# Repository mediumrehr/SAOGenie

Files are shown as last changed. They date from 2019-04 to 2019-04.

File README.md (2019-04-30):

# SAOGenie

The SAO Genie was inspired by the [TPM Genie](https://github.com/nccgroup/TPMGenie), specially crafted for attacking [Shitty Add-ons](https://hackaday.com/2018/06/21/this-is-the-year-conference-badges-get-their-own-badges/) at DEF CON 26. The SAO Genie was designed as a tool for electronic badge and add-on hacking, since it provides an easier interface for sniffing and manipulating data on the serial bus between a badge and targeted add-on. As electronic badges are being used more frequently in conference hacking challenges, the SAO Genie is geared to make it easier to dig into inter-badge/add-on communications.

The SAO Genie works by sitting between an electronic badge and a targeted add-on as a man-in-the-middle kind of way. The SAO Genie is able to do this by acting as a slave to the conference badge, pretending to be the targeted add-on (using the same i2c address), while also playing the role of master to the targeted add-on (forwarding and possibly manipulating) serial data packets between the badge and target add-on. The SAO Genie has both a 2x2 male header for plugging into a conference badge, and a 2x2 female header for providing a connector for the targeted add-on to connect to.

## Functionality

Currently, only monitor/passthrough mode is supported.

#### Monitor/Passthrough Mode

When placed between an electronic badge and targeted add-on, the SAO Genie will forward all communications between the type pieces of hardware, while also repeating any data out through the UART serial port.

Connect the SAO Genie as shown below:

To connect to the UART serial port, attach your serial reader to the RX, TX, and GND pins on the 'handle'.

Serial settings:

```
Baudrate: 9600
Data bits: 8
Parity: None
Stop bits: 1
```

## Installing/Updating Firmware

### Setup

Firmware can be loaded with [Atmel Studio 7.0](https://www.microchip.com/mplab/avr-support/atmel-studio-7), or install the packages below to use with your preferred text editor and compile with arm gcc.

#### arm gcc and gdb

MacOS

```
brew install armmbed/formulae/arm-none-eabi-gcc
```

#### jlink gdb server

Download install file from [segger.com](https://www.segger.com/products/debug-probes/j-link/tools/j-link-gdb-server/about-j-link-gdb-server/)

#### SWD connection

Software debug (SWD) pins are labelled on the back of the board. Connect SWDIO, SWCLK, 3V3, RESET, and GND as labelled. SWD requires the board to be powered external from the SWD port, so it's easiest to power the board from the 3V3 and GND pins on one of the SAO headers.

### Build

```
cd firmware/SAOGenie/
make -C Build/
```

### Load

#### jlink

Start jlink gdb server in one tab

```
JLinkGDBServer -if SWD -device ATSAMD21G18
```

Start gdb in another tba

```
arm-none-eabi-gdb Build/SAOGenie.elf
(gdb) target extended-remote :2331
```

Load new firmware, reset microcontroller, and run new code

```
(gdb) load
(gdb) monitor reset
(gdb) c
```

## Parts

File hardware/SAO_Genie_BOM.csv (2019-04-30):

DEF CON 26 SAO Genie Add-on Bill of Materials
April 2019
@mediumrehr
Part | Value | Package | Part Number | Description | Digikey link | notes
C6, 8, 10-12 | 0.1uF | 603 |  | Capacitor
C7, 9 | 22pF | 603 |  | Capacitor
D1 | amber | 1206 |  | LED
J1 | 2x2 | 0.1" pitch |  | SAO Male header Connector
J2 | 2x2 | 0.1" pitch |  | SAO Female header Connector
L1 | FB - 30Ohm | 603 |  | Inductor
R3, 4, 11 | 10K | 805 |  | Resistor
R5 | 68 | 603 |  | Resistor
U4 |  | 48-TQFP | ATSAMD21G18A | IC MCU 32BIT 256KB FLASH | https://www.digikey.com/product-detail/en/microchip-technology/ATSAMD21G18A-AUT/ATSAMD21G18A-AUTCT-ND/4878879
Y1 | 32.768KHz | 2-SMD | ABS06-127-32.768KHZ-T | Crystal | https://www.digikey.com/product-detail/en/abracon-llc/ABS06-127-32.768KHZ-T/535-14513-1-ND/8827204

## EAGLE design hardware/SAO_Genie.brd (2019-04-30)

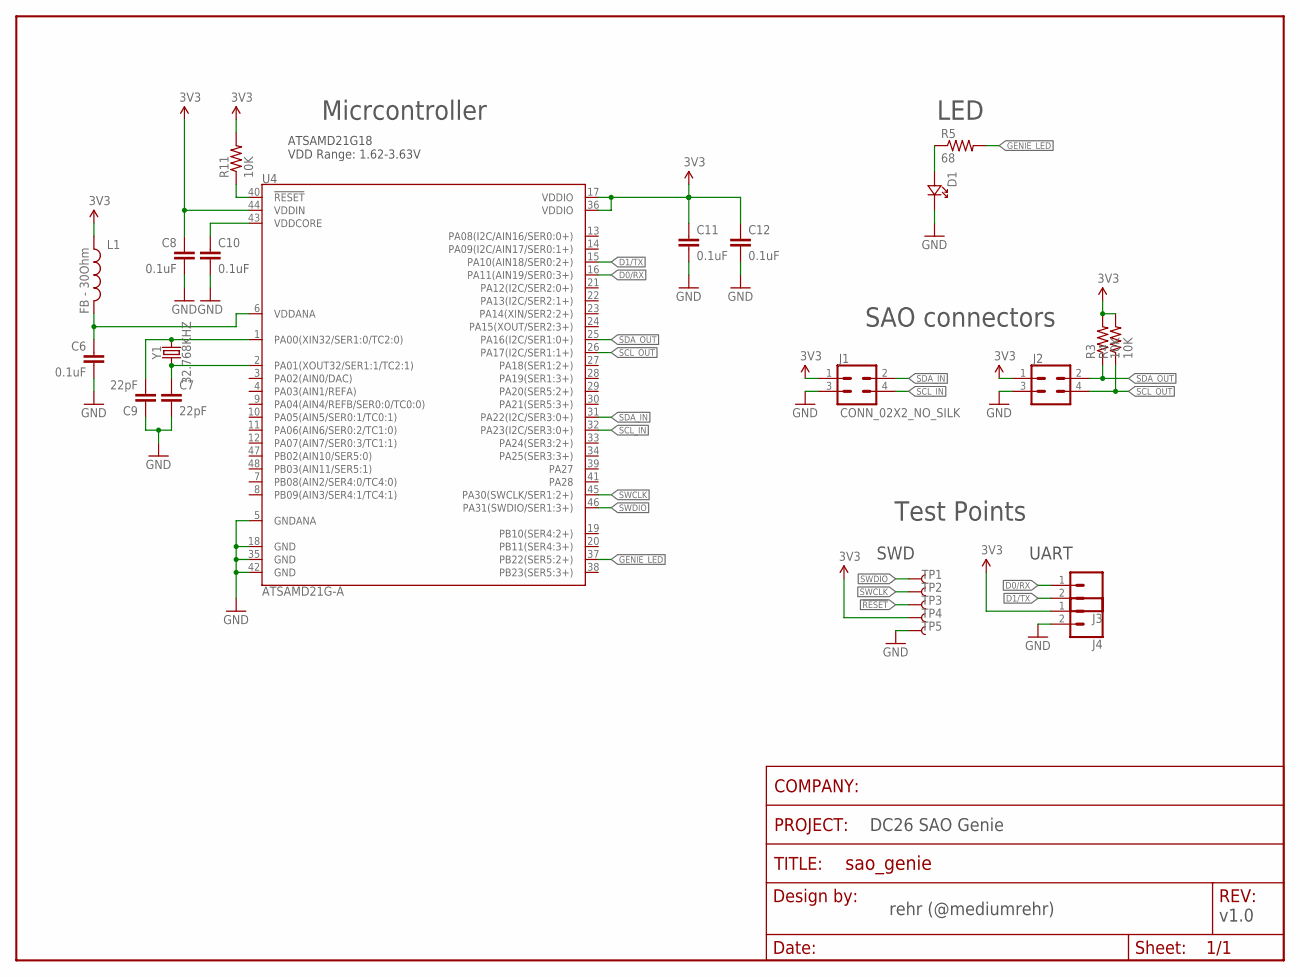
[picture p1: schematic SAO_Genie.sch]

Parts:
C6, C8, C10, C11, C12: 0.1uF; 0603-CAP
C7, C9: 22pF; 0603-CAP
D1: LED1206REVERSE_NO_SILK; 1206_NO_SILK
FRAME1: FRAME-LETTER-BLANKNO_PACKAGE; DUMMY
J1: CONN_02X2_NO_SILK; 2X2_NO_SILK
J2: SAO OUT; 2X2_NO_SILK
J3, J4: CONN_021X02_NO_SILK; 1X02_NO_SILK
L1: FB - 30Ohm; 0603
R3, R4, R11: 10K; 0603-RES
R5: 68; 0603-RES
TP1, TP2, TP3, TP4, TP5: TEST-POINT3X5; PAD.03X.05
U4: ATSAMD21G-A; TQFP-48
Y1: 32.768KHZ; ABS06

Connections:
3.3V: C8.1, C11.1, C12.1, J1.1, J2.1, J4.1, L1.1, R3.2, R4.2, R11.2, TP4.P$1, U4.17 (VDDIO), U4.36 (VDDIO), U4.44 (VDDIN)
!RESET: R11.1, TP3.P$1, U4.40 (!RESET!)
D0/RX: J3.1, U4.16 (PA11(AIN19/SER0:3+))
D1/TX: J3.2, U4.15 (PA10(AIN18/SER0:2+))
GENIE_LED: R5.2, U4.37 (PB22(SER5:2+))
GND: C6.2, C7.2, C8.2, C9.1, C10.2, C11.2, C12.2, D1.P$1, J1.3, J2.3, J4.2, TP5.P$1, U4.5 (GNDANA), U4.18 (GND), U4.35 (GND), U4.42 (GND)
unnamed: C7.1, U4.2 (PA01(XOUT32/SER1:1/TC2:1)), Y1.P$1 (1)
unnamed: D1.P$2, R5.1
unnamed: C9.2, U4.1 (PA00(XIN32/SER1:0/TC2:0)), Y1.P$2 (2)
SCL_IN: J1.4, U4.32 (PA23(I2C/SER3:0+))
SCL_OUT: J2.4, R4.1, U4.26 (PA17(I2C/SER1:1+))
SDA_IN: J1.2, U4.31 (PA22(I2C/SER3:0+))
SDA_OUT: J2.2, R3.1, U4.25 (PA16(I2C/SER1:0+))
SWCLK: TP2.P$1, U4.45 (PA30(SWCLK/SER1:2+))
SWDIO: TP1.P$1, U4.46 (PA31(SWDIO/SER1:3+))
VDDANA: C6.1, L1.2, U4.6 (VDDANA)
VDDCORE: C10.1, U4.43 (VDDCORE)

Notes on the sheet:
ATSAMD21G18 VDD Range: 1.62-3.63V
DC26 SAO Genie
rehr (@mediumrehr)
v1.0
Micrcontroller
LED
SAO connectors
Test Points
SWD
UART

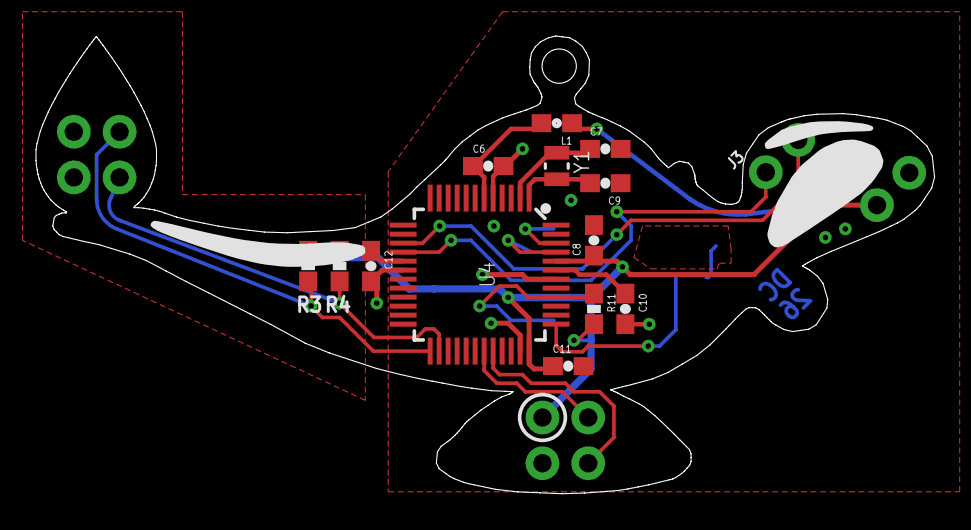
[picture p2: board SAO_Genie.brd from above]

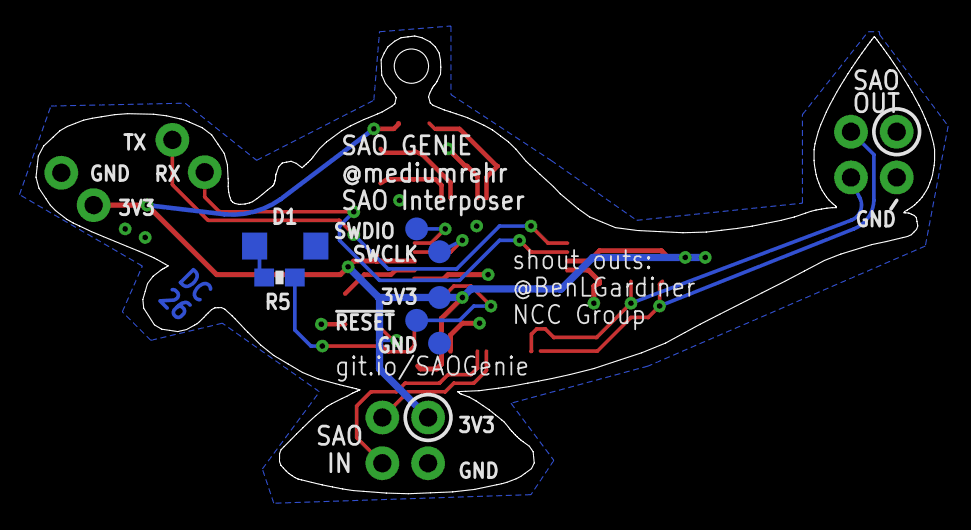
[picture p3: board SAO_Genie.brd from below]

Board: 2 copper layers, 49.9 x 25.4 mm, 25 parts (7 on the bottom side), 17 nets.

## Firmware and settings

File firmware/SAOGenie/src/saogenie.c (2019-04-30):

/**
 * 
 * SAOGenie
 * Shitty add-on hacking tool
 * Rob Rehr
 * @mediumrehr
 *
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
 * 3. The name of Atmel may not be used to endorse or promote products derived
 *    from this software without specific prior written permission.
 *
 * 4. This software may only be redistributed and used in connection with an
 *    Atmel microcontroller product.
 *
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
 */

#include <asf.h>
#include <stdio.h>
#include <string.h>

void i2c_read_request_callback(struct i2c_slave_module *const module);
void i2c_slave_read_complete_callback(struct i2c_slave_module *const module);
void i2c_write_request_callback(struct i2c_slave_module *const module);
void i2c_slave_write_complete_callback(struct i2c_slave_module *const module);
void usart_read_callback(struct usart_module *const usart_module);
void usart_write_callback(struct usart_module *const usart_module);
void i2c_write_complete_callback(struct i2c_master_module *const module);

void configure_i2c_slave(void);
void configure_i2c_slave_callbacks(void);
void configure_i2c_master(void);
void configure_i2c_master_callbacks(void);
void configure_usart(void);
void configure_usart_callbacks(void);

void set_genie_mode(uint8_t new_mode);

// i2c packets
#define PACKET_BUFFER_SIZE 50
static uint8_t dest_addr = 0;
static struct i2c_slave_packet packet_in;
struct i2c_master_packet wr_packet_out;
struct i2c_master_packet rd_packet_out;

#define DATA_LENGTH 50
static uint8_t write_buffer_in[DATA_LENGTH];
static uint8_t read_buffer_in [DATA_LENGTH];

static uint8_t write_buffer_out[DATA_LENGTH];
static uint8_t read_buffer_out[DATA_LENGTH];

// SAO Genie mode definitions
#define GENIE_MODE_OFF 			0
#define GENIE_MODE_PASSTHROUGH 	1
#define GENIE_MODE_REDIRECT		2 // not implememnted
#define GENIE_MODE_INJECT		3 // not implemented

uint8_t genie_mode = GENIE_MODE_OFF;

// Init device instance
struct i2c_slave_module i2c_slave_instance;
struct i2c_master_module i2c_master_instance;
struct usart_module usart_instance;

#define MAX_RX_BUFFER_LENGTH   1
volatile uint8_t rx_buffer[MAX_RX_BUFFER_LENGTH];

void i2c_read_request_callback(struct i2c_slave_module *const module) {
	// Init i2c packet
	packet_in.data_length = DATA_LENGTH;
	packet_in.data        = write_buffer_in;

	// Write buffer to master
	i2c_slave_write_packet_job(module, &packet_in);
}

void i2c_write_request_callback(struct i2c_slave_module *const module) {	
	// init i2c packet
	packet_in.data_length = DATA_LENGTH;
	packet_in.data        = read_buffer_in;
	
	// store intended destination for packet
	dest_addr = module->hw->I2CS.DATA.reg >> 1;

	// read buffer from master
	i2c_slave_read_packet_job(module, &packet_in);
}

void i2c_slave_write_complete_callback(struct i2c_slave_module *const module) {
	uint8_t temp[] = "test";
	usart_write_buffer_wait(&usart_instance, temp, sizeof(temp));
}

void i2c_slave_read_complete_callback(struct i2c_slave_module *const module) {
	// make sure SAO Genie mode is not set to off
	if (genie_mode == GENIE_MODE_PASSTHROUGH) {
		// turn i2c LED on to show activity
		port_pin_set_output_level(LEDI2C_PIN, true);
		
		// copy serial data locally to pass along
		uint8_t genie_dest_addr = dest_addr;
		uint8_t bytes_received = module->buffer_received;
		
		// copy destination and data to output packet for master to send
		wr_packet_out.address	  = genie_dest_addr;
		wr_packet_out.data_length = bytes_received;
		wr_packet_out.data        = &read_buffer_in[0];

		// send output packet out master
		i2c_master_write_packet_wait(&i2c_master_instance, &wr_packet_out);

		// print i2c direction and addresses
		char dirStr[29] = {0};
		snprintf(dirStr, sizeof(dirStr), "| Host > Genie > 0x%02X       ", genie_dest_addr);
		usart_write_buffer_wait(&usart_instance, dirStr, sizeof(dirStr));

		// print i2c data captured to uart
		usart_write_buffer_wait(&usart_instance, "| ", sizeof("| "));
		uint8_t i = 0;
		while(read_buffer_in[i] != 0) {
			uint8_t tempStr[4] = {0};
			snprintf(tempStr, sizeof(tempStr), "%02X ", read_buffer_in[i]);
			usart_write_buffer_wait(&usart_instance, tempStr, sizeof(tempStr));
			i++;
		}
		usart_write_buffer_wait(&usart_instance, "\n", sizeof("\n"));
		
		// toggle LED to show activity
		port_pin_set_output_level(LEDI2C_PIN, false);
	}
}

void i2c_write_complete_callback(struct i2c_master_module *const module) {
	// initiate new packet read
	i2c_master_read_packet_job(&i2c_master_instance,&rd_packet_out);
}

void usart_read_callback(struct usart_module *const usart_module) {
	// no user input currently
	// major to do item
}

void usart_write_callback(struct usart_module *const usart_module) {
	
}

void configure_i2c_slave(void) {
	// initialize config for i2c slave
	struct i2c_slave_config config_i2c_slave;
	i2c_slave_get_config_defaults(&config_i2c_slave);

	// set slave to respond to any address between 0x00 and 0xFF
	config_i2c_slave.address	  = 0xFF; // upper i2c address range
	config_i2c_slave.address_mask = 0x00; // lower i2c address range
	config_i2c_slave.address_mode = I2C_SLAVE_ADDRESS_MODE_RANGE;
	config_i2c_slave.pinmux_pad0  = PINMUX_PA22C_SERCOM3_PAD0;
	config_i2c_slave.pinmux_pad1  = PINMUX_PA23C_SERCOM3_PAD1;

	// initialize and enable i2c slave with config
	while(i2c_slave_init(&i2c_slave_instance, SERCOM3, &config_i2c_slave) != STATUS_OK);
	i2c_slave_enable(&i2c_slave_instance);
}

void configure_i2c_slave_callbacks(void) {
	// Register and enable i2c slave callback functions
	i2c_slave_register_callback(&i2c_slave_instance, i2c_read_request_callback,
		I2C_SLAVE_CALLBACK_READ_REQUEST);
	i2c_slave_register_callback(&i2c_slave_instance, i2c_slave_read_complete_callback,
		I2C_SLAVE_CALLBACK_READ_COMPLETE);
	i2c_slave_register_callback(&i2c_slave_instance, i2c_write_request_callback,
		I2C_SLAVE_CALLBACK_WRITE_REQUEST);
	i2c_slave_register_callback(&i2c_slave_instance, i2c_slave_write_complete_callback,
		I2C_SLAVE_CALLBACK_WRITE_COMPLETE);

	i2c_slave_enable_callback(&i2c_slave_instance, I2C_SLAVE_CALLBACK_READ_REQUEST);
	i2c_slave_enable_callback(&i2c_slave_instance, I2C_SLAVE_CALLBACK_READ_COMPLETE);
	i2c_slave_enable_callback(&i2c_slave_instance, I2C_SLAVE_CALLBACK_WRITE_REQUEST);
	i2c_slave_enable_callback(&i2c_slave_instance, I2C_SLAVE_CALLBACK_WRITE_COMPLETE);
}

void configure_usart(void) {
	// initialize config for uart
	struct usart_config config_usart;
	usart_get_config_defaults(&config_usart);

	// set uart baudrate and uart pins
	config_usart.baudrate    = 9600;
	config_usart.mux_setting = EXT1_UART_SERCOM_MUX_SETTING;
	config_usart.pinmux_pad0 = EXT1_UART_SERCOM_PINMUX_PAD0;
	config_usart.pinmux_pad1 = EXT1_UART_SERCOM_PINMUX_PAD1;
	config_usart.pinmux_pad2 = EXT1_UART_SERCOM_PINMUX_PAD2;
	config_usart.pinmux_pad3 = EXT1_UART_SERCOM_PINMUX_PAD3;

	// initialize and enable uart with config
	while (usart_init(&usart_instance, EXT1_UART_MODULE, &config_usart) != STATUS_OK);
	usart_enable(&usart_instance);
}

void configure_usart_callbacks(void) {
	// register and enable uart callback functions
	usart_register_callback(&usart_instance,
		usart_write_callback, USART_CALLBACK_BUFFER_TRANSMITTED);
	usart_register_callback(&usart_instance,
		usart_read_callback, USART_CALLBACK_BUFFER_RECEIVED);

	usart_enable_callback(&usart_instance, USART_CALLBACK_BUFFER_TRANSMITTED);
	usart_enable_callback(&usart_instance, USART_CALLBACK_BUFFER_RECEIVED);
}

void configure_i2c_master(void) {
	// initialize config for i2c master
	struct i2c_master_config config_i2c_master;
	i2c_master_get_config_defaults(&config_i2c_master);

	// set buffer timerout and pins
	config_i2c_master.buffer_timeout = 65535;
	config_i2c_master.pinmux_pad0    = PINMUX_PA16C_SERCOM1_PAD0;
	config_i2c_master.pinmux_pad1    = PINMUX_PA17C_SERCOM1_PAD1;

	// initialize and enable i2c master with config
	while(i2c_master_init(&i2c_master_instance, SERCOM1, &config_i2c_master) != STATUS_OK);
	i2c_master_enable(&i2c_master_instance);
}

void configure_i2c_master_callbacks(void)
{
	// Register and enable i2c master callback functions
	i2c_master_register_callback(&i2c_master_instance, \
		i2c_write_complete_callback, I2C_MASTER_CALLBACK_WRITE_COMPLETE);

	i2c_master_enable_callback(&i2c_master_instance, I2C_MASTER_CALLBACK_WRITE_COMPLETE);
}

static void config_led(void) {
	// initialize config for pins
	struct port_config pin_conf;
	port_get_config_defaults(&pin_conf);

	// set direction, apply config, and set output to off
	pin_conf.direction  = PORT_PIN_DIR_OUTPUT;
	port_pin_set_config(LEDI2C_PIN, &pin_conf);
	port_pin_set_output_level(LEDI2C_PIN, false);
}

void set_genie_mode(uint8_t new_mode) {
	// switch and print new SAO Genie mode
	switch(new_mode) {
		case GENIE_MODE_PASSTHROUGH:
		; // print new mode
		uint8_t printStr1[] = "|                           | [*] mode set to: passthrough\n";
		usart_write_buffer_wait(&usart_instance, printStr1, sizeof(printStr1));
		break;

		case GENIE_MODE_REDIRECT:
		; // print new mode
		uint8_t printStr3[] = "|                           | [*] mode set to: redirect\n";
		usart_write_buffer_wait(&usart_instance, printStr3, sizeof(printStr3));
		break;

		case GENIE_MODE_INJECT:
		; // print new mode
		uint8_t printStr2[] = "|                           | [*] mode set to: inject\n";
		usart_write_buffer_wait(&usart_instance, printStr2, sizeof(printStr2));
		break;

		default:
		; // default/off
		uint8_t printStr0[] = "|                           | [*] mode set to: off\n";
		usart_write_buffer_wait(&usart_instance, printStr0, sizeof(printStr0));
		break;
	}

	genie_mode = new_mode;
}

int main(void) {

	system_init();

	configure_i2c_slave();
	configure_i2c_slave_callbacks();
	
	configure_i2c_master();
	configure_i2c_master_callbacks();
	
	configure_usart();
	configure_usart_callbacks();
	
	config_led();

	system_interrupt_enable_global();

	uint8_t aboutStr[] = "\n********************\n   SAO GENIE v0.1\n     mediumrehr\n********************\n\n";
	usart_write_buffer_wait(&usart_instance, aboutStr, sizeof(aboutStr));

	uint8_t headerStr[] = "/---------------------------|-------------------------------------------------\\\n|         Direction         |  Data                                           |\n|---------------------------|-------------------------------------------------|\n";
	usart_write_buffer_wait(&usart_instance, headerStr, sizeof(headerStr));

	set_genie_mode(GENIE_MODE_PASSTHROUGH);

	while (true) {
		// loop and wait for uart input
		usart_read_buffer_job(&usart_instance, (uint8_t *)rx_buffer, MAX_RX_BUFFER_LENGTH);
	}
}

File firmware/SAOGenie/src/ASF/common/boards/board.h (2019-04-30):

/**
 * \file
 *
 * \brief Standard board header file.
 *
 * This file includes the appropriate board header file according to the
 * defined board (parameter BOARD).
 *
 * Copyright (c) 2009-2016 Atmel Corporation. All rights reserved.
 *
 * \asf_license_start
 *
 * \page License
 *
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
 * 3. The name of Atmel may not be used to endorse or promote products derived
 *    from this software without specific prior written permission.
 *
 * 4. This software may only be redistributed and used in connection with an
 *    Atmel microcontroller product.
 *
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
 * \asf_license_stop
 *
 */
/*
 * Support and FAQ: visit <a href="http://www.atmel.com/design-support/">Atmel Support</a>
 */

#ifndef _BOARD_H_
#define _BOARD_H_

/**
 * \defgroup group_common_boards Generic board support
 *
 * The generic board support module includes board-specific definitions
 * and function prototypes, such as the board initialization function.
 *
 * \{
 */

#include "compiler.h"

#ifdef __cplusplus
extern "C" {
#endif


/*! \name Base Boards
 */
//! @{
#define EVK1100                     1  //!< AT32UC3A EVK1100 board.
#define EVK1101                     2  //!< AT32UC3B EVK1101 board.
#define UC3C_EK                     3  //!< AT32UC3C UC3C-EK board.
#define EVK1104                     4  //!< AT32UC3A3 EVK1104 board.
#define EVK1105                     5  //!< AT32UC3A EVK1105 board.
#define STK600_RCUC3L0              6  //!< STK600 RCUC3L0 board.
#define UC3L_EK                     7  //!< AT32UC3L-EK board.
#define XPLAIN                      8  //!< ATxmega128A1 Xplain board.
#define STK600_RC064X              10  //!< ATxmega256A3 STK600 board.
#define STK600_RC100X              11  //!< ATxmega128A1 STK600 board.
#define UC3_A3_XPLAINED            13  //!< ATUC3A3 UC3-A3 Xplained board.
#define UC3_L0_XPLAINED            15  //!< ATUC3L0 UC3-L0 Xplained board.
#define STK600_RCUC3D              16  //!< STK600 RCUC3D board.
#define STK600_RCUC3C0             17  //!< STK600 RCUC3C board.
#define XMEGA_B1_XPLAINED          18  //!< ATxmega128B1 Xplained board.
#define XMEGA_A1_XPLAINED          19  //!< ATxmega128A1 Xplain-A1 board.
#define XMEGA_A1U_XPLAINED_PRO     20  //!< ATxmega128A1U XMEGA-A1U Xplained Pro board.
#define STK600_RCUC3L4             21  //!< ATUCL4 STK600 board.
#define UC3_L0_XPLAINED_BC         22  //!< ATUC3L0 UC3-L0 Xplained board controller board.
#define MEGA1284P_XPLAINED_BC      23  //!< ATmega1284P-Xplained board controller board.
#define STK600_RC044X              24  //!< STK600 with RC044X routing card board.
#define STK600_RCUC3B0             25  //!< STK600 RCUC3B0 board.
#define UC3_L0_QT600               26  //!< QT600 UC3L0 MCU board.
#define XMEGA_A3BU_XPLAINED        27  //!< ATxmega256A3BU Xplained board.
#define STK600_RC064X_LCDX         28  //!< XMEGAB3 STK600 RC064X LCDX board.
#define STK600_RC100X_LCDX         29  //!< XMEGAB1 STK600 RC100X LCDX board.
#define UC3B_BOARD_CONTROLLER      30  //!< AT32UC3B1 board controller for Atmel boards.
#define RZ600                      31  //!< AT32UC3A RZ600 MCU board.
#define SAM3S_EK                   32  //!< SAM3S-EK board.
#define SAM3U_EK                   33  //!< SAM3U-EK board.
#define SAM3X_EK                   34  //!< SAM3X-EK board.
#define SAM3N_EK                   35  //!< SAM3N-EK board.
#define SAM3S_EK2                  36  //!< SAM3S-EK2 board.
#define SAM4S_EK                   37  //!< SAM4S-EK board.
#define STK600_RCUC3A0             38  //!< STK600 RCUC3A0 board.
#define STK600_MEGA                39  //!< STK600 MEGA board.
#define MEGA_1284P_XPLAINED        40  //!< ATmega1284P Xplained board.
#define SAM4S_XPLAINED             41  //!< SAM4S Xplained board.
#define ATXMEGA128A1_QT600         42  //!< QT600 ATXMEGA128A1 MCU board.
#define ARDUINO_DUE_X              43  //!< Arduino Due/X board.
#define STK600_RCUC3L3             44  //!< ATUCL3 STK600 board.
#define SAM4L_EK                   45  //!< SAM4L-EK board.
#define STK600_MEGA_RF             46  //!< STK600 MEGA RF EVK board.
#define XMEGA_C3_XPLAINED          47  //!< ATxmega384C3 Xplained board.
#define STK600_RC032X              48  //!< STK600 with RC032X routing card board.
#define SAM4S_EK2                  49  //!< SAM4S-EK2 board.
#define XMEGA_E5_XPLAINED          50  //!< ATxmega32E5 Xplained board.
#define SAM4E_EK                   51  //!< SAM4E-EK board.
#define ATMEGA256RFR2_XPLAINED_PRO 52  //!< ATmega256RFR2 Xplained Pro board.
#define SAM4S_XPLAINED_PRO         53  //!< SAM4S Xplained Pro board.
#define SAM4L_XPLAINED_PRO         54  //!< SAM4L Xplained Pro board.
#define ATMEGA256RFR2_ZIGBIT       55  //!< ATmega256RFR2 zigbit.
#define XMEGA_RF233_ZIGBIT         56  //!< ATxmega256A3U with AT86RF233 Zigbit.
#define XMEGA_RF212B_ZIGBIT        57  //!< ATxmega256A3U with AT86RF212B Zigbit.
#define SAM4S_WPIR_RD              58  //!< SAM4S-WPIR-RD board.
#define SAMD20_XPLAINED_PRO        59  //!< SAM D20 Xplained Pro board.
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

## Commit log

2018-07-24 add eagle design files
    [SAO_Genie.brd, SAO_Genie.sch]
2019-04-30 update hardware schematic, board layout, and bill of material
    [SAO_Genie.brd, SAO_Genie.sch, SAO_Genie_BOM.csv]

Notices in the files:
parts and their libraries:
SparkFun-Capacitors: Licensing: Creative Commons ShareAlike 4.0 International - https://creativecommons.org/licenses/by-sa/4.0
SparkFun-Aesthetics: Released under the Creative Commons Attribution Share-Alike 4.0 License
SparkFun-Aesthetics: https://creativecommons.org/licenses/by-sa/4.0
